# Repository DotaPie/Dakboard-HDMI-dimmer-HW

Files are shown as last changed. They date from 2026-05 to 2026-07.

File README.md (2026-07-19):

# Dakboard HDMI Dimmer - Hardware

A Raspberry Pi HAT that carries a BH1750 ambient-light sensor and a PIR motion sensor for automatic HDMI display dimming.

Designed for the Raspberry Pi Zero 2 W, but it mounts on any Raspberry Pi with the standard 40-pin header. Pairs with [Dakboard-HDMI-dimmer-FW](https://github.com/DotaPie/Dakboard-HDMI-dimmer-FW), which reads these sensors and adjusts display brightness.

## What's on the board

- **40-pin GPIO header (J1)** - mounts the board as a HAT and breaks out power, I²C, and the PIR line
- **BH1750 light sensor header (J2)** - 5-pin module (VCC / GND / SCL / SDA / ADDR) on I²C bus 1, address `0x23`, with 4K7 pull-ups
- **PIR motion sensor header (J3)** - 3-pin module (VCC / OUT / GND) with the output on GPIO24 (BCM), physical pin 18
- Decoupling and signal-conditioning passives, plus four mounting holes

The BH1750 runs at 3.3 V on the Pi's primary I²C bus; the PIR is powered from 5 V and its output is fed to a GPIO. All dimming logic lives in the firmware - this board just carries the sensors.

## Pin usage

| Signal | Raspberry Pi pin | Notes |
|---|---|---|
| I²C SDA  | GPIO2 / pin 3 | BH1750 (bus 1, addr `0x23`)  |
| I²C SCL  | GPIO3 / pin 5 | BH1750 |
| PIR out  | GPIO24 / pin 18 | Motion detection |
| 3V3 | pin 1 | BH1750 supply |
| 5V | pin 2 / pin 4 | PIR supply |
| GND | pins 6, 9, 14, … | Common ground |

## Board specs

- Size: **30 × 65 mm**
- 4× mounting holes
- 2-layer, JLCPCB-ready gerbers included

## Repository layout

```
Dakboard HDMI dimmer KiCAD/
└─ Dakboard HDMI dimmer v1/
   ├─ Dakboard HDMI dimmer v1.kicad_pro   # KiCAD project
   ├─ Dakboard HDMI dimmer v1.kicad_sch   # schematic
   ├─ Dakboard HDMI dimmer v1.kicad_pcb   # PCB layout
   └─ gerber_to_order/                    # zipped gerbers for JLCPCB
```

## Manufacturing

The gerber archive in `gerber_to_order/` is ready to upload to [JLCPCB](https://jlcpcb.com/) (or any fabricator) as-is. To modify the design, open the project in [KiCAD](https://www.kicad.org/) 7 or newer.

## Below is an example of full HW installation with custom cabling

Snímka obrazovky 2026-07-19 014746





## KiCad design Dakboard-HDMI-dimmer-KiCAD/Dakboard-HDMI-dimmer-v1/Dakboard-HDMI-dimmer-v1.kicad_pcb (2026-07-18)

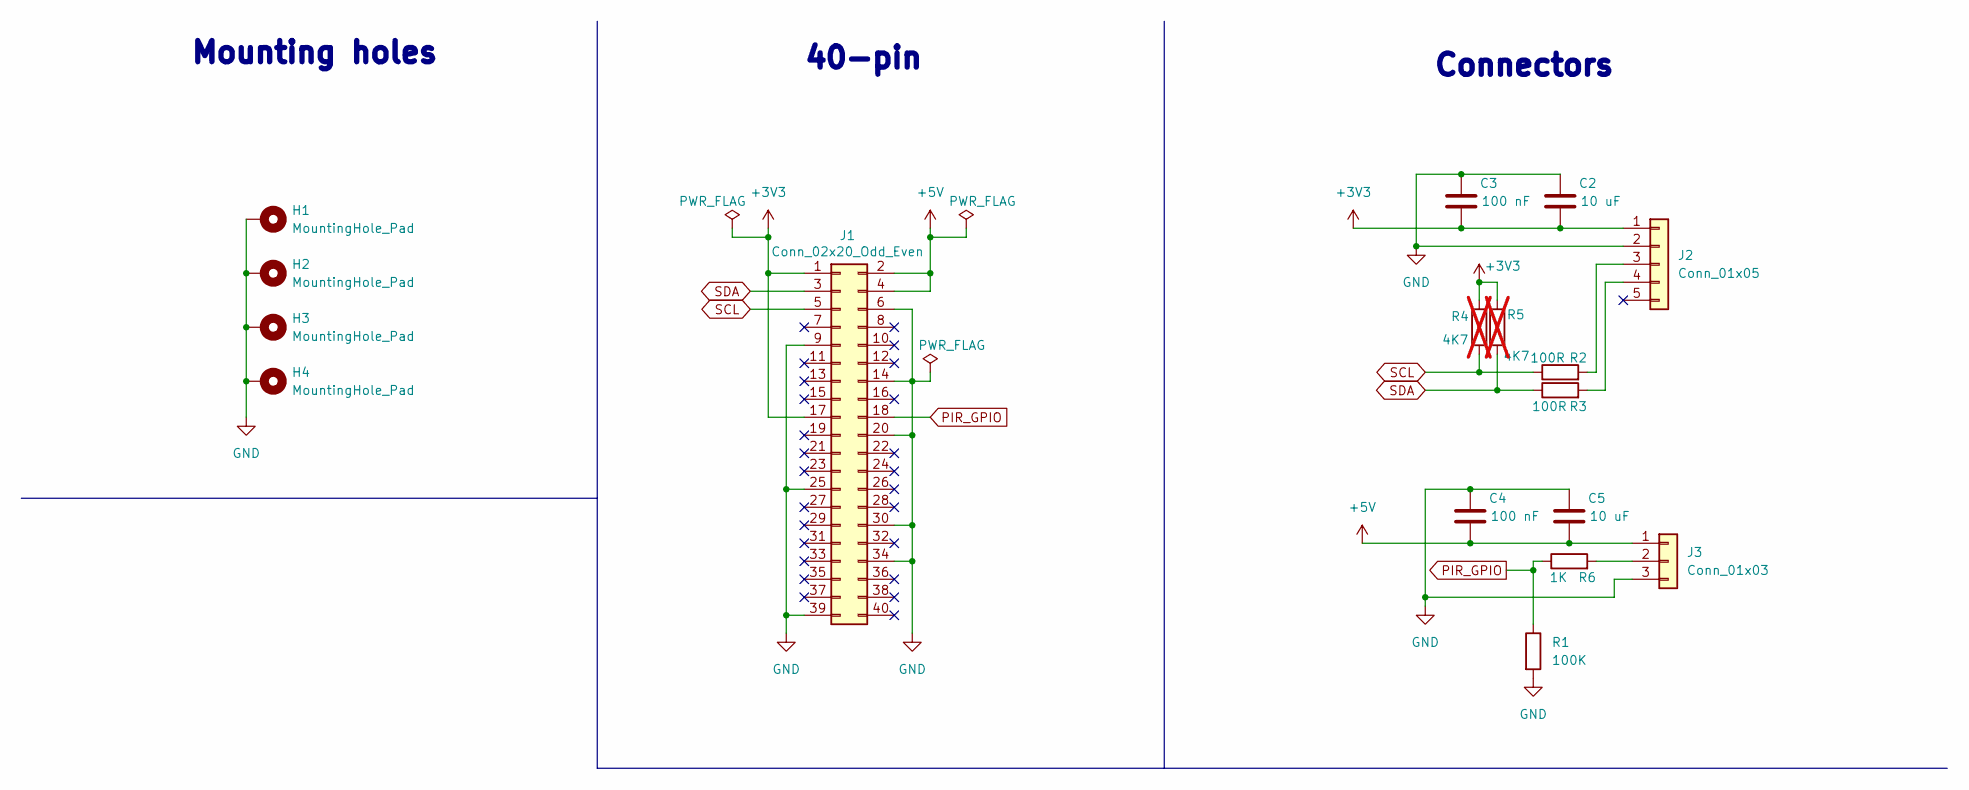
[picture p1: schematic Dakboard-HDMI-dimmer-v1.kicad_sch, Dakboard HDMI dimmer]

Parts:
C2, C5: 10 uF; C_0805_2012Metric_Pad1.18x1.45mm_HandSolder
C3, C4: 100 nF; C_0805_2012Metric_Pad1.18x1.45mm_HandSolder
H1, H2, H3, H4: MountingHole_Pad; MountingHole_2.5mm_Pad
J1: Conn_02x20_Odd_Even; PinSocket_2x20_P2.54mm_Vertical
J2: Conn_01x05; PinHeader_1x05_P2.54mm_Horizontal
J3: Conn_01x03; PinHeader_1x03_P2.54mm_Horizontal
R1: 100K; R_0805_2012Metric_Pad1.20x1.40mm_HandSolder
R2, R3: 100R; R_0805_2012Metric_Pad1.20x1.40mm_HandSolder
R4, R5: 4K7; R_0805_2012Metric_Pad1.20x1.40mm_HandSolder; not fitted
R6: 1K; R_0805_2012Metric_Pad1.20x1.40mm_HandSolder

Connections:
+3V3: C2.2, C3.2, J1.1, J1.17, J2.1, R4.1, R5.1
+5V: C4.2, C5.2, J1.2, J1.4, J3.1
GND: C2.1, C3.1, C4.1, C5.1, H1.1 (1_1), H2.1 (1_1), H3.1 (1_1), H4.1 (1_1), J1.6, J1.9, J1.14, J1.20, J1.25, J1.30, J1.34, J1.39, J2.2, J3.3, R1.2
unnamed: J2.3, R2.2
unnamed: J2.4, R3.2
unnamed: J3.2, R6.2
PIR_GPIO: J1.18, R1.1, R6.1
SCL: J1.5, R2.1, R4.2
SDA: J1.3, R3.1, R5.2

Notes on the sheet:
Mounting holes
40-pin
Connectors

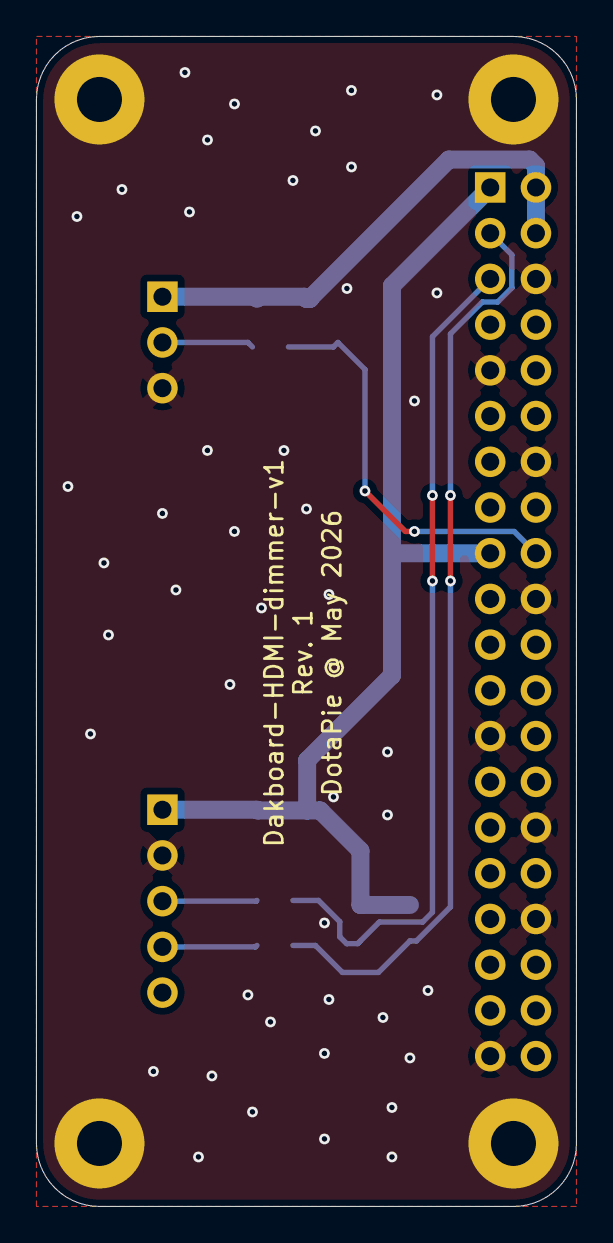
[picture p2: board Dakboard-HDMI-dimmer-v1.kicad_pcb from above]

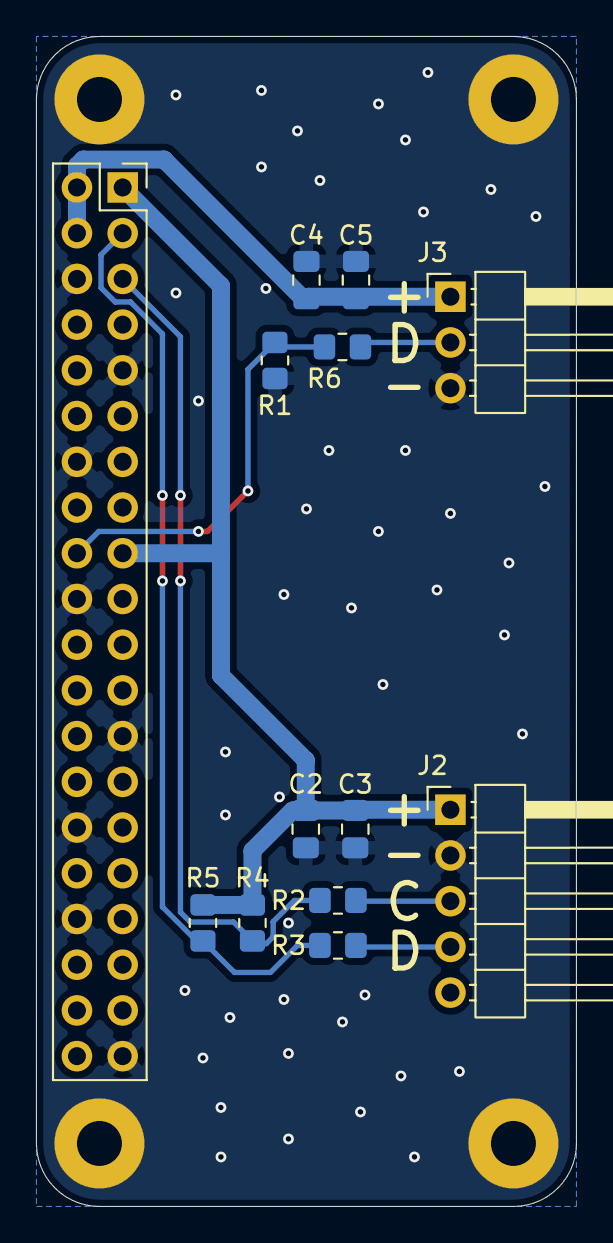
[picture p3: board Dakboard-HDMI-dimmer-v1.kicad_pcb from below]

Board: 2 copper layers, 30.0 x 65.0 mm, 17 parts (13 on the bottom side), 9 nets.

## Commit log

2026-05-10 Init project
    [Mainboard v1.kicad_pcb, Mainboard v1.kicad_sch]
2026-05-10 Fixed path
    [Mainboard v1.kicad_pcb, Mainboard v1.kicad_sch]
2026-05-16 schematic, BOM, board wip
    [Mainboard v1.kicad_pcb, Mainboard v1.kicad_sch]
2026-05-16 Board routing, cleanup, jlcpcb export
    [Dakboard HDMI dimmer v1.kicad_pcb, Dakboard HDMI dimmer v1.kicad_sch, Mainboard v1.kicad_pcb]
2026-06-02 Changed R I2C protective to 100R (was 47R)
    [Dakboard HDMI dimmer v1.kicad_sch]
